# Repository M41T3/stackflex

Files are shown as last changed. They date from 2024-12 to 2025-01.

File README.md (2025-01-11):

# What is StackFlex?

**StackFlex** is a microcontroller system built around the Espressif ESP32-S3 Mini module. The heart of the system is the **Core PCB**, which houses the microprocessor and supports power delivery via USB or a LiPo battery. Additional functionalities can be seamlessly integrated through modular **Feature PCBs**, which are designed to stack on top of the Core PCB.

The StackFlex system is highly extensible and flexible, all within a compact 40 mm x 40 mm form factor. Leveraging the advanced capabilities of the ESP32-S3 — such as Bluetooth LE, WiFi, and more — the innovative stacking mechanism, and templates for custom Feature PCBs, the system offers virtually unlimited use cases, constrained only by your imagination.

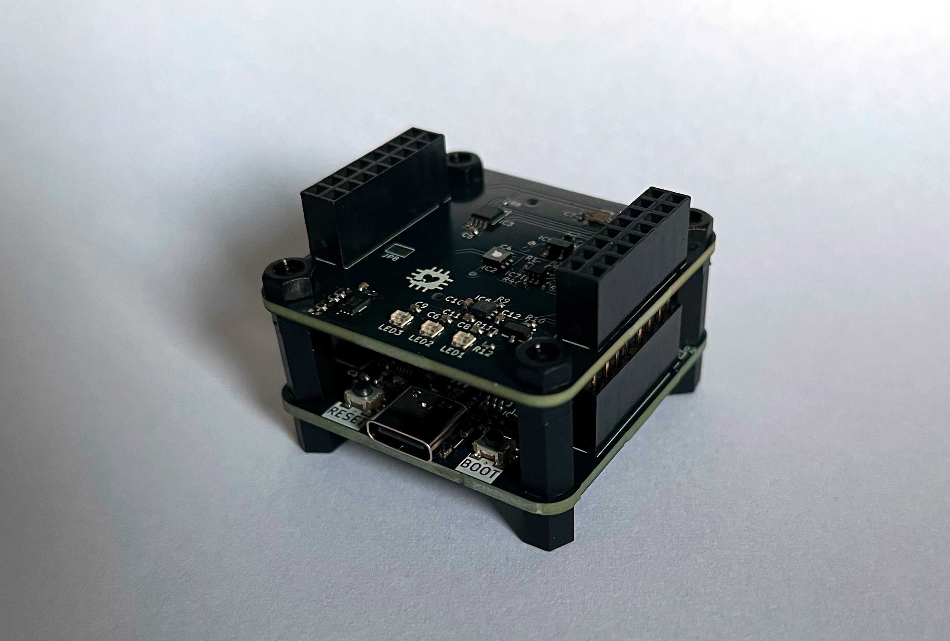
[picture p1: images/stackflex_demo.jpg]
System Image


# Contents

- KiCad Projects
- PDF Schematics
- JLCPCB Production Files (Gerber, BOM, CPL)
- StackFlex Arduino Library *[tbd]* 

# Core PCB Highlights

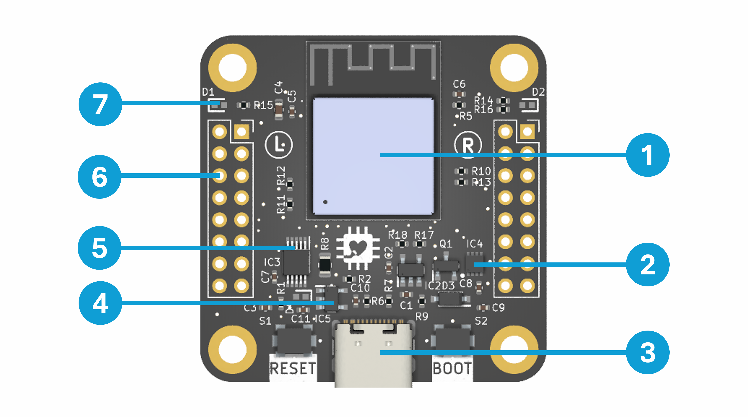
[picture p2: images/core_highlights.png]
Core Front


1. **ESP32-S3 Mini 1 Module:** Powerful and energy-efficient microcontroller featuring dual-core processing, integrated WiFi and Bluetooth LE connectivity, AI acceleration, and extensive peripheral support.

2. **3.7 V LiPo:** Power StackFlex using a LiPo battery with state-of-charge (SOC) monitoring.

3. **USB C Connector:** State of the art connector to programm and power the microcontroller and its peripherals.

4. **LiPo Charging:** LiPo charges via USB if it is connected.

5. **Power Monitoring:** Monitor the power consumption and current of stacked Feature PCBs.

6. **GPIO:** Rotationally symmetrical GPIOs for enhanced flexibility.

7. **LEDs:** Two status LEDs (red, green)

=> Detailed documentation [here](/pcb/stackflex_core/).

# Feature PCBs

Feature PCBs enhance the fucntionality of the StackFlex system. Here is a list of already developed Feature PCBs:

- [Air Quality Feature PCB](/pcb/stackflex_feature_air_qual/)
    - Gas Sensor (TVOC, eCO2)
    - Temperature
    - Ambient Light Sensor
    - WS2812B Status LEDs
- more to come..

# Feature PCB Template

Develop and build your own Feature PCB with the provided KiCad Template Project.

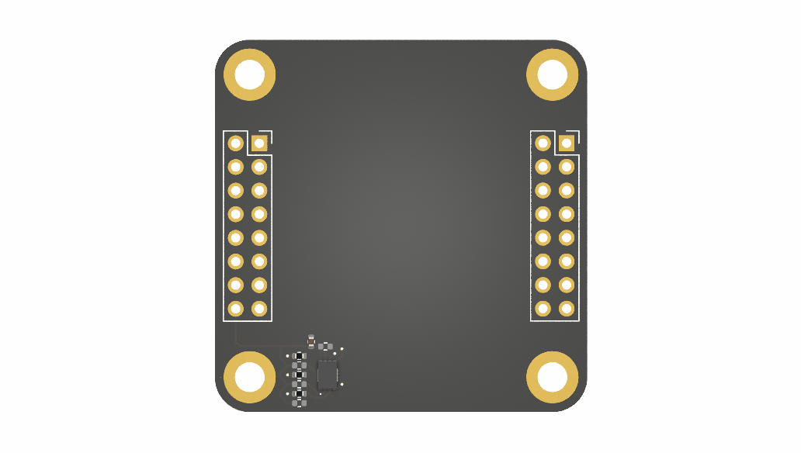
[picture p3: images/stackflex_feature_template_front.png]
Feature PCB Template


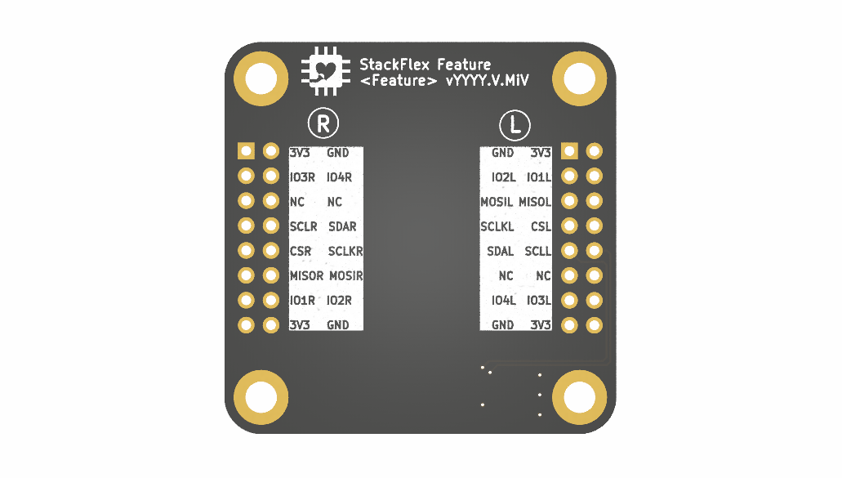
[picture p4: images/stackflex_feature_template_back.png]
Feature PCB Template


=> Detailed documentation [here](/pcb/stackflex_feature_template/).

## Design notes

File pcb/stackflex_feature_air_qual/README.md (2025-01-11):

# StackFlex Air Quality Feature PCB

**Sensors**:

- [LM75 Temperature Sensor](https://www.analog.com/media/en/technical-documentation/data-sheets/lm75.pdf)
- [OPT3001 Ambient Light Sensor (ALS)](https://www.ti.com/lit/ds/symlink/opt3001.pdf?ts=1736604398451)
- [SGP30 Indoor Air Quality Sensor](https://sensirion.com/media/documents/984E0DD5/61644B8B/Sensirion_Gas_Sensors_Datasheet_SGP30.pdf)

See schematic for further information.

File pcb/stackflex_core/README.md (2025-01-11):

# StackFlex Core

**Pinout:** 

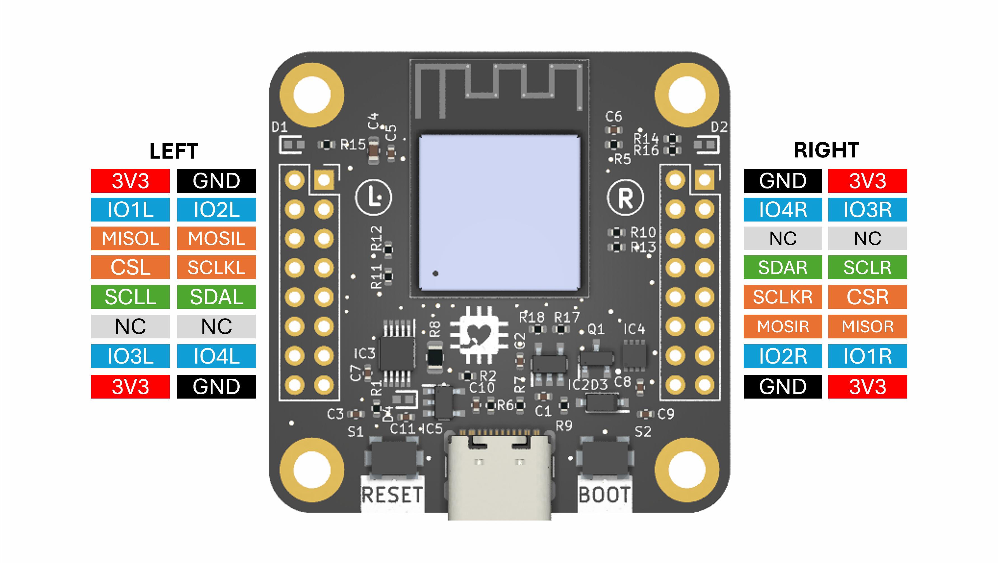
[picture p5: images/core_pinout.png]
Core Front


**Backside:**

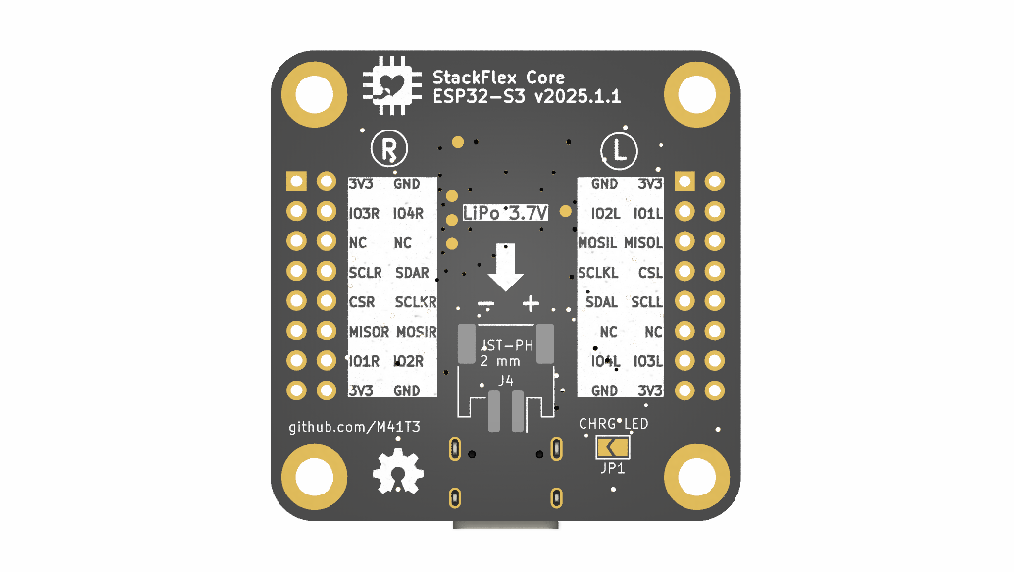
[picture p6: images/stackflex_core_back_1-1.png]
Core Back


- JST-PH 2mm Connector Footprint for LiPo (check polarity)

**ICs:**
- [ESP32-S3 Mini](https://www.espressif.com/sites/default/files/documentation/esp32-s3-mini-1_mini-1u_datasheet_en.pdf)
- [INA226 Current Sensor](https://www.ti.com/lit/ds/symlink/ina226.pdf)
- [TP4054 Battery Charger](https://www.laskakit.cz/user/related_files/tp4054.pdf)
- [MAX17048 Battery Fuel Gauge](https://www.analog.com/media/en/technical-documentation/data-sheets/MAX17048-MAX17049.pdf)

See schematic for further information.

**Assembly:**

- Pinheader 2x8 2.54 mm
- M3 Spacer

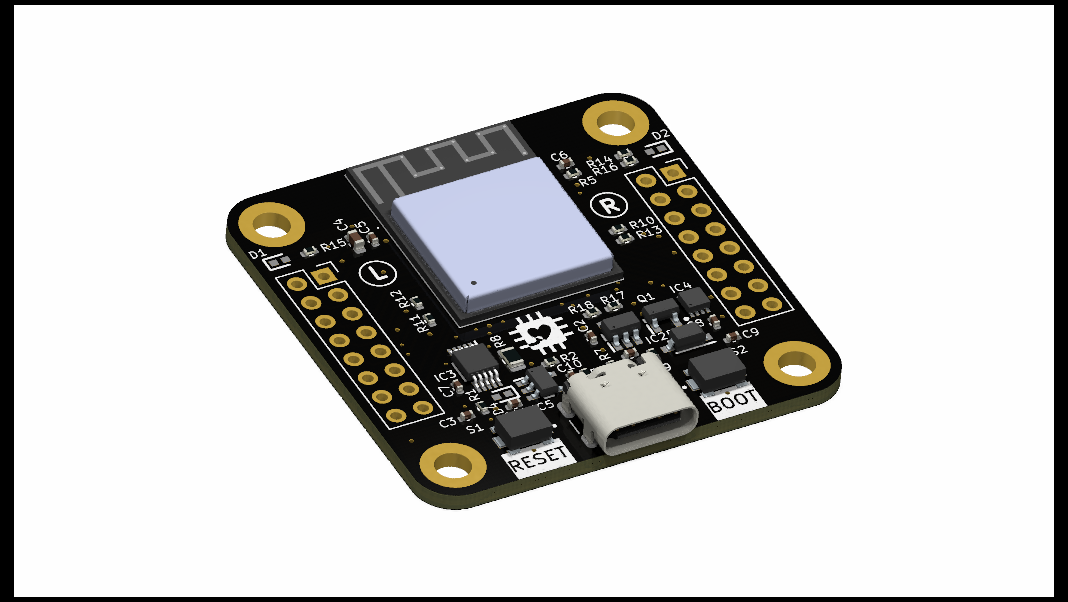
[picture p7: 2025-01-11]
images/stackflex_core_side_1-1.png

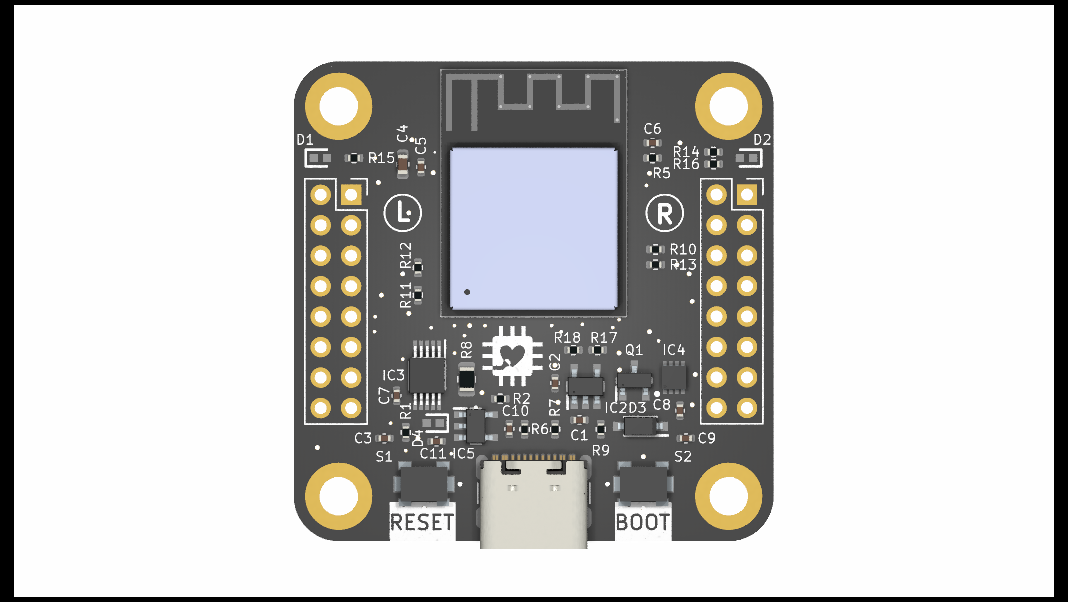
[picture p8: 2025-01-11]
images/stackflex_core_front_1-1.png

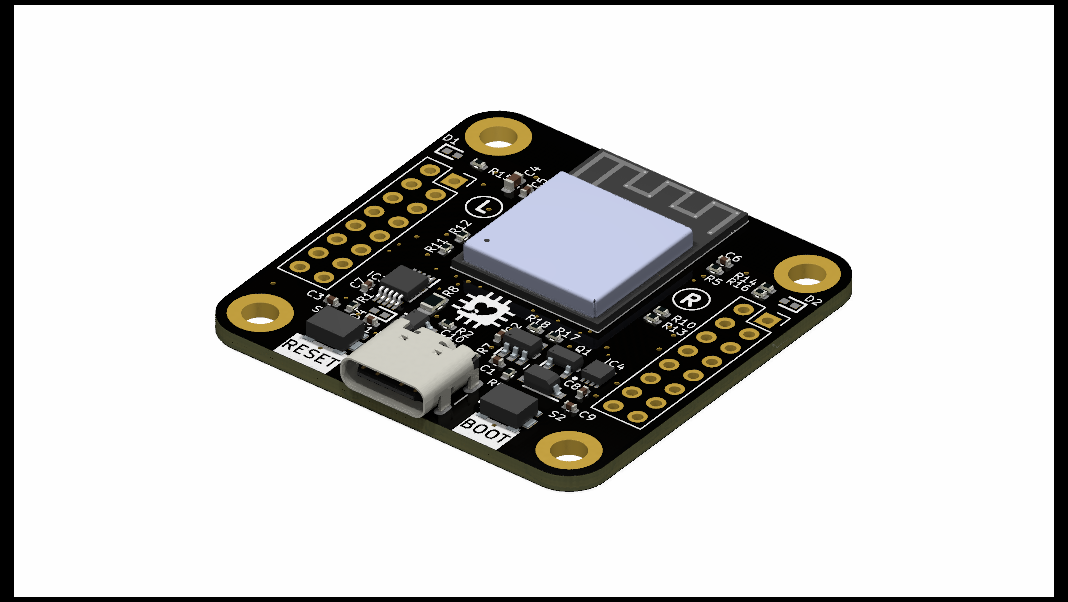
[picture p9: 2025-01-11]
images/stackflex_core_side2_1-1.png

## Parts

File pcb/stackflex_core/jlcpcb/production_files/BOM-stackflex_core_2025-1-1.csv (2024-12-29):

Comment | Designator | Footprint | LCSC | Quantity
1k | R1 | R_0402_1005Metric | C11702 | 1
0.1uF | C3,C5,C6,C7,C8,C9 | C_0402_1005Metric | C1525 | 6
10uF | C1,C11 | C_0402_1005Metric | C15525 | 2
USB_C_Receptacle_USB2.0_16P | J1 | USB_C_Receptacle_GCT_USB4105-xx-A_16P_TopMnt_Horizontal | C165948 | 1
PTS820J25MSMTRLFS | S1,S2 | PTS820J25MSMTRLFS | C221900 | 2
33 mOhm 1% 250mW | R8 | R_0805_2012Metric | C247604 | 1
330 | R14,R16 | R_0402_1005Metric | C25104 | 2
33 | R15 | R_0402_1005Metric | C25105 | 1
100k | R9 | R_0402_1005Metric | C25741 | 1
10k | R5 | R_0402_1005Metric | C25744 | 1
4.7k | R10,R11,R12,R13,R17,R18 | R_0402_1005Metric | C25900 | 6
5.1k 1% | R6,R7 | R_0402_1005Metric | C25905 | 2
MAX17048G+T10 | IC4 | SON50P200X200X80-9N-D | C2682616 | 1
ESP32-S3-MINI-1-N8 | IC1 | ESP32S3MINI1N8 | C2913206 | 1
2k | R2 | R_0402_1005Metric | C4109 | 1
DMP2045U-7 | Q1 | SOT96P240X115-3N | C459541 | 1
INA226AIDGSR | IC3 | SOP50P490X110-10N | C49851 | 1
AP2112K-3.3TRG1 | IC2 | SOT95P285X140-5N | C51118 | 1
1uF | C10,C2 | C_0402_1005Metric | C52923 | 2
22uF | C4 | C_0603_1608Metric | C59461 | 1
TP4054 | IC5 | SOT95P280X100-5N | C668215 | 1
green | D1,D4 | LEDC1005X55N | C71911 | 2
red | D2 | LEDC1005X55N | C74338 | 1
1N5819HW-7-F | D3 | SOD3716X145N | C82544 | 1

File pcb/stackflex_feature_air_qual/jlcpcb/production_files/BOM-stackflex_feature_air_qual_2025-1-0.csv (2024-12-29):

Comment | Designator | Footprint | LCSC | Quantity
BSS138BK | Q3 | TL431CDBZR215 | C112239 | 1
2.2uF | C11,C12 | C_0402_1005Metric | C12530 | 2
0.1uF | C1,C5,C6,C7,C8,C9 | C_0402_1005Metric | C1525 | 6
SolderJumper_2_Open | JP2,JP5,JP7 | R_0402_1005Metric | C17168 | 3
TPS60150DRVR | IC6 | SON65P200X200X80-7N | C182429 | 1
BSS138PS | IC7 | SOT65P210X110-6N | C193381 | 1
4.7uF | C10 | C_0402_1005Metric | C23733 | 1
470 | R12 | R_0402_1005Metric | C25117 | 1
10k | R1,R10,R11,R2,R3,R4,R7,R8,R9 | R_0402_1005Metric | C25744 | 9
LM75BDP,118 | IC3 | SOP65P490X110-8N | C33099 | 1
XL-0807RGBC-WS2812B | LED1,LED2,LED3 | XL0807RGBCWS2812B | C3646929 | 3
M24C02-RMC6TG | IC1 | M24C16RMC6TG | C495258 | 1
SGP30-2.5k | IC2 | SON80P245X245X90-7N | C514454 | 1
1uF | C2,C3,C4 | C_0402_1005Metric | C52923 | 3
TLV70018DDCR | IC5 | SOT95P280X110-5N | C79924 | 1
OPT3001DNPR | IC4 | SON65P200X200X65-7N-D | C90462 | 1

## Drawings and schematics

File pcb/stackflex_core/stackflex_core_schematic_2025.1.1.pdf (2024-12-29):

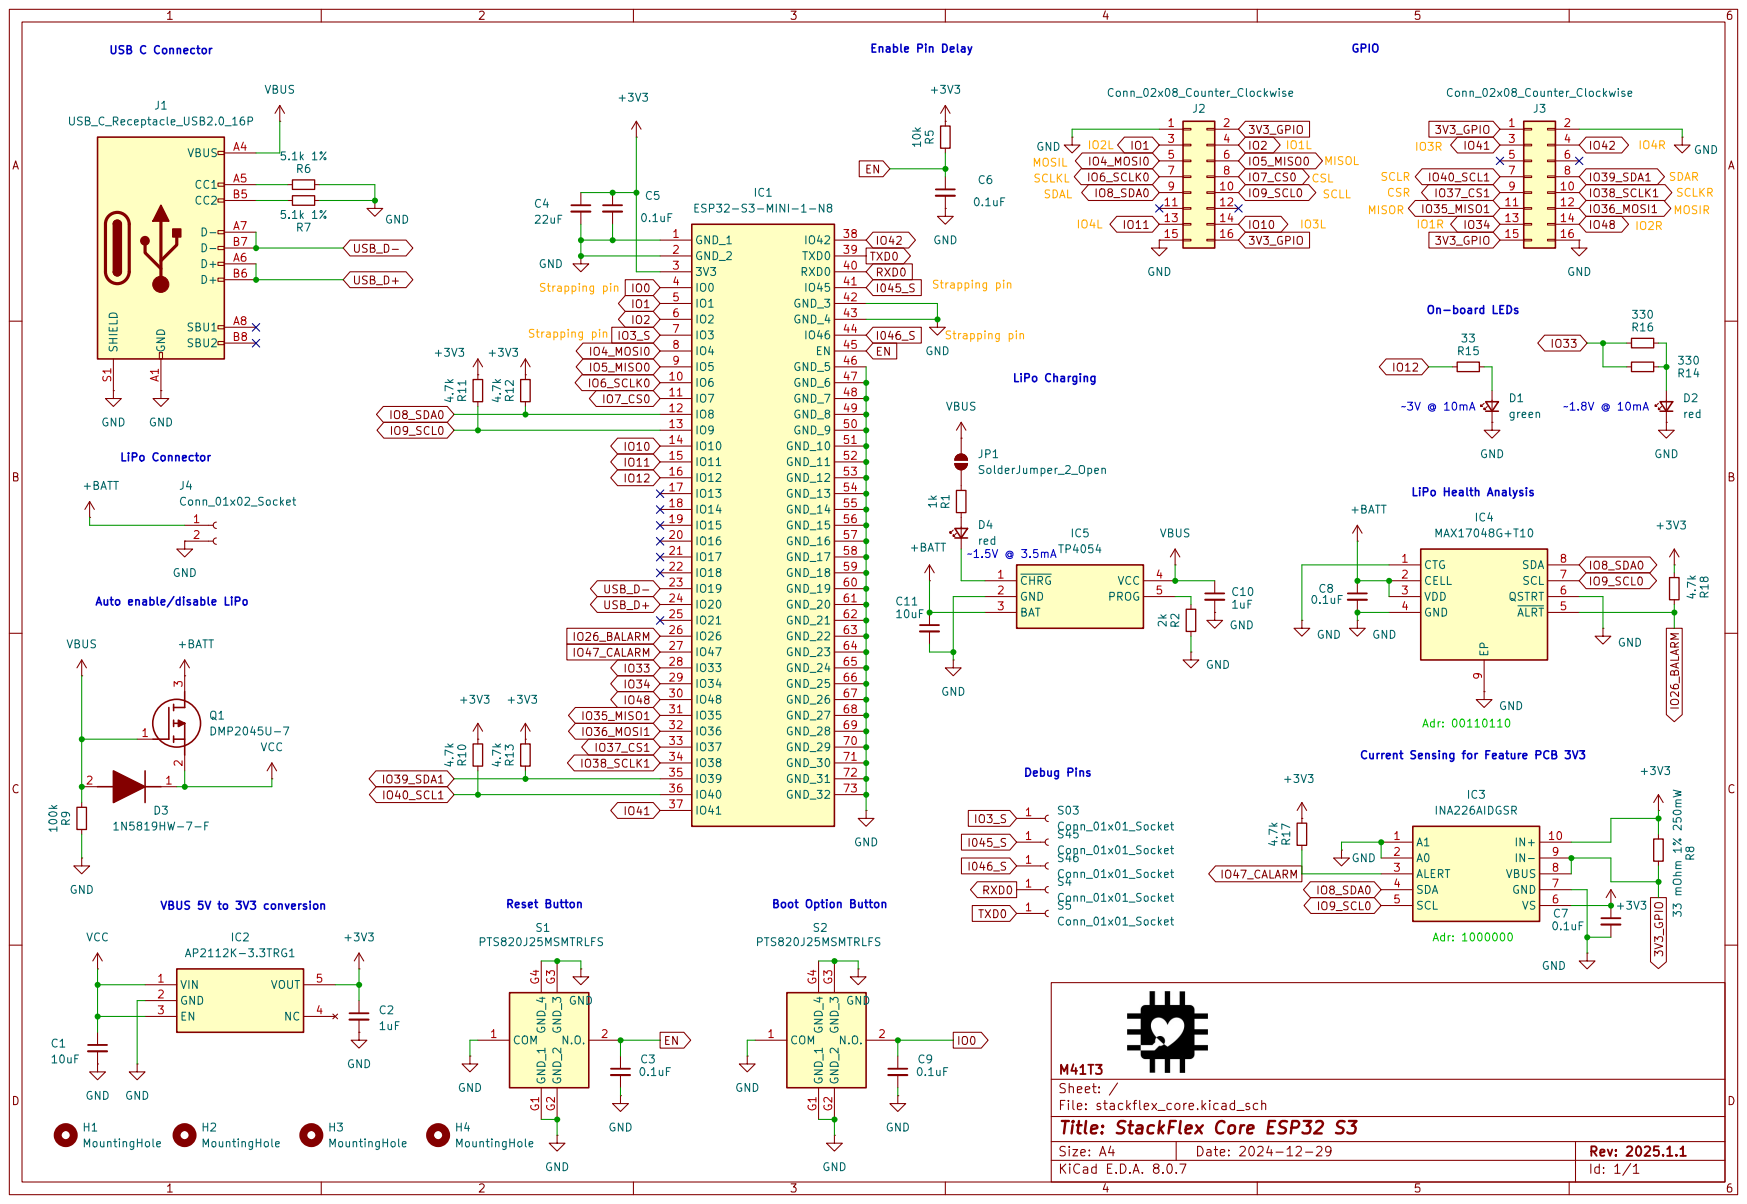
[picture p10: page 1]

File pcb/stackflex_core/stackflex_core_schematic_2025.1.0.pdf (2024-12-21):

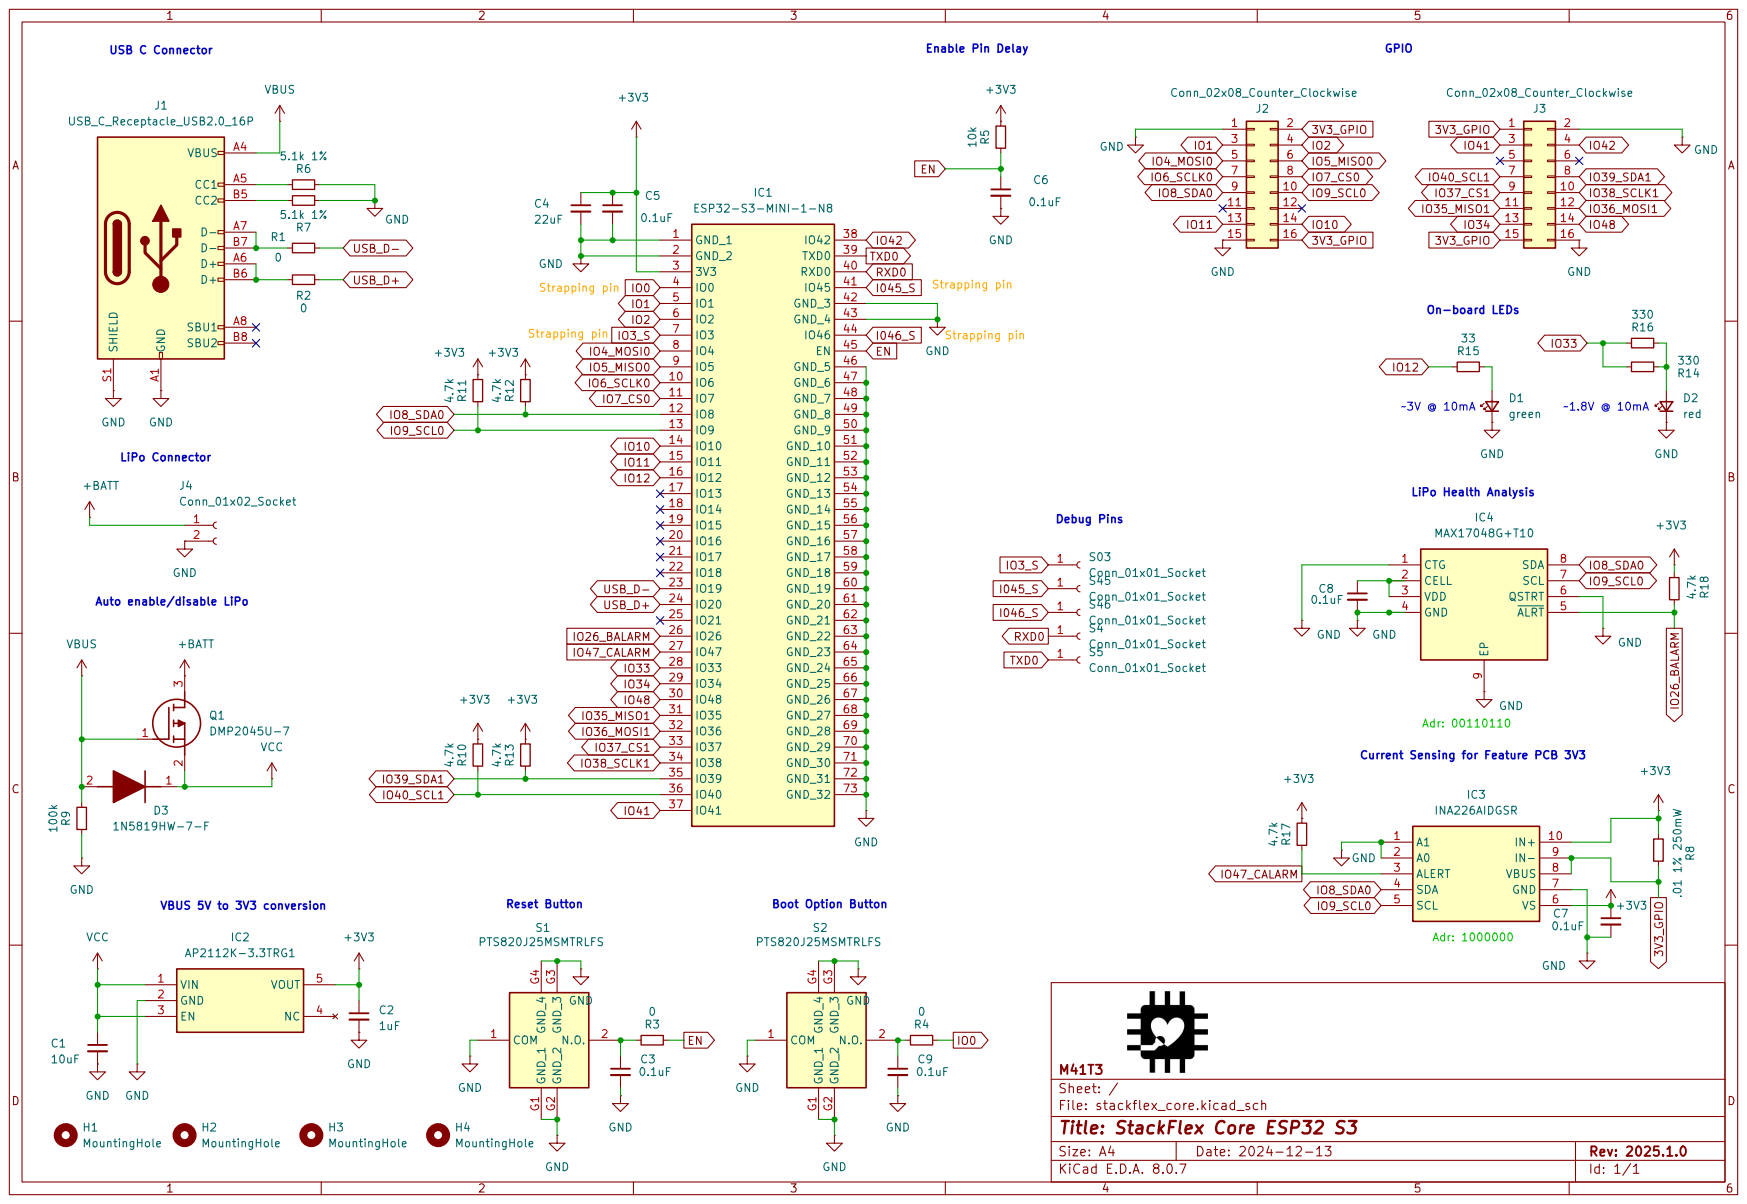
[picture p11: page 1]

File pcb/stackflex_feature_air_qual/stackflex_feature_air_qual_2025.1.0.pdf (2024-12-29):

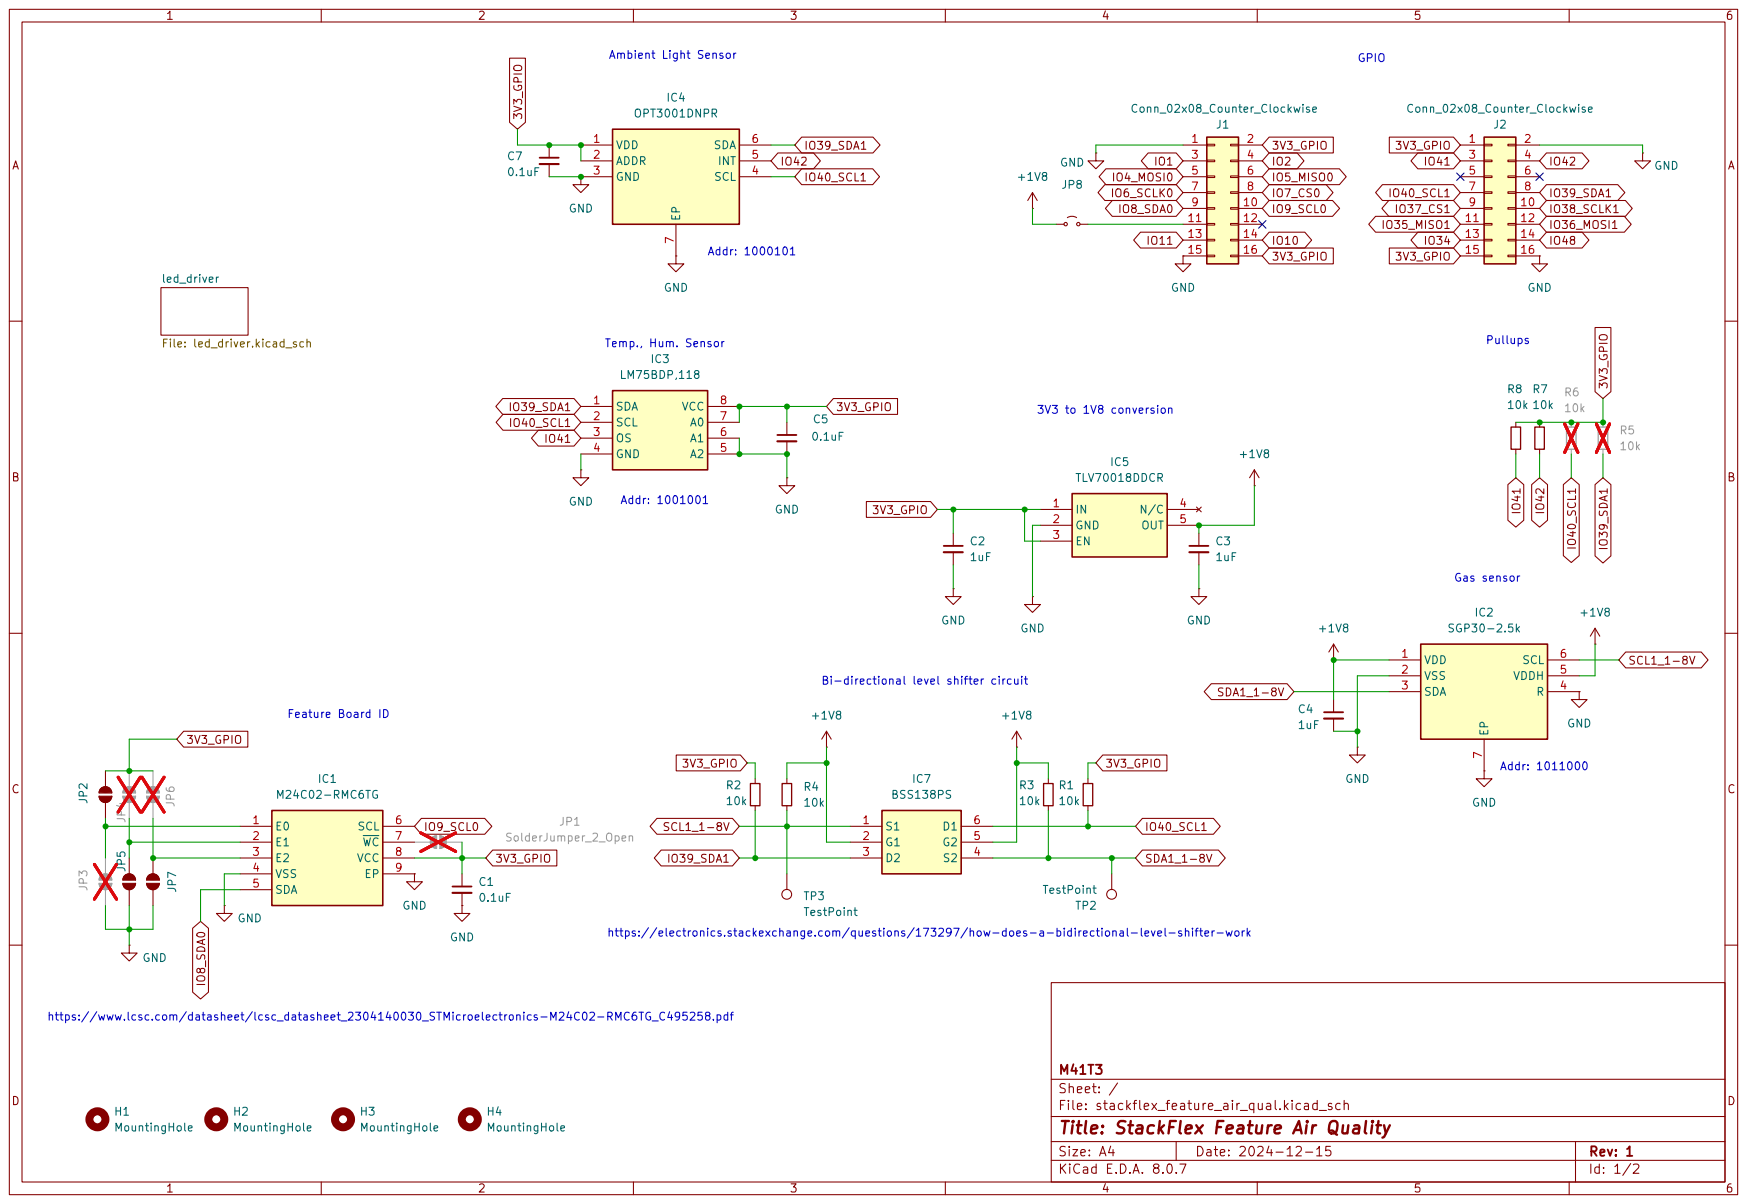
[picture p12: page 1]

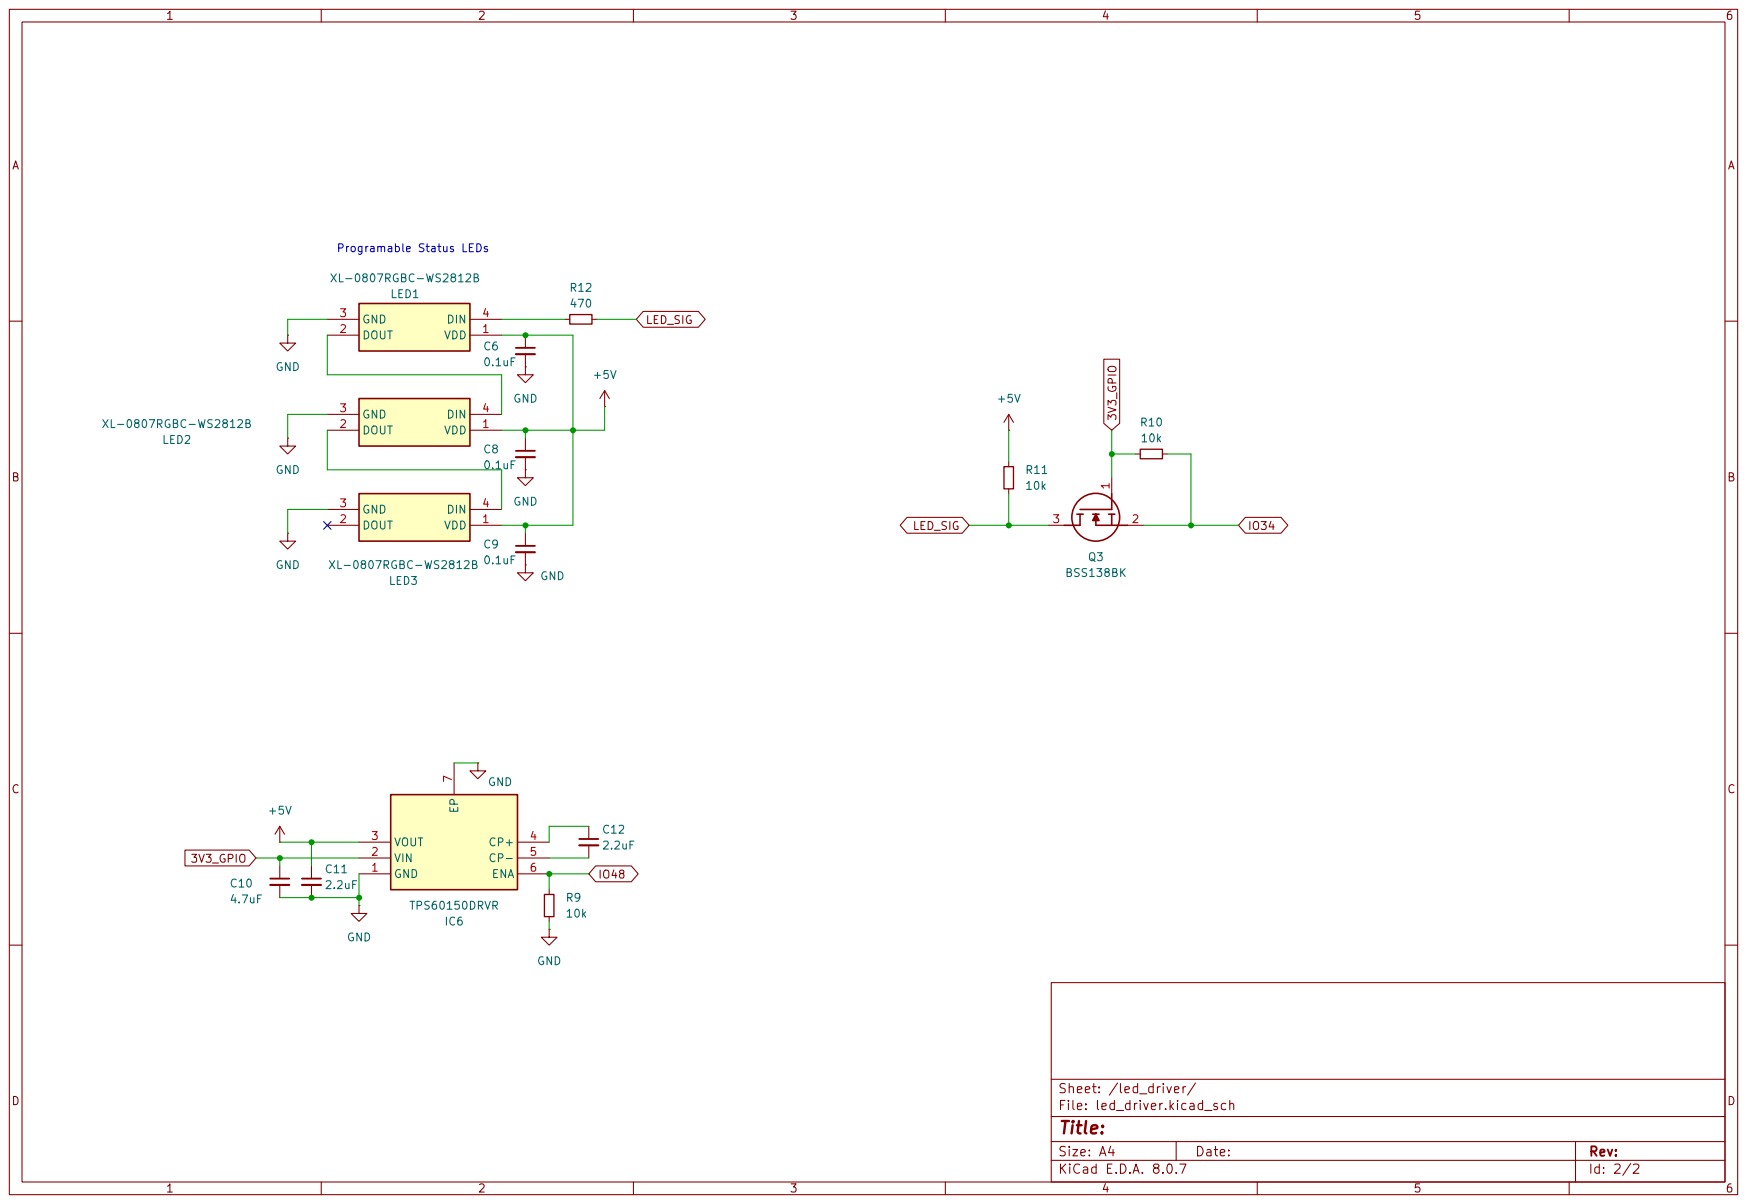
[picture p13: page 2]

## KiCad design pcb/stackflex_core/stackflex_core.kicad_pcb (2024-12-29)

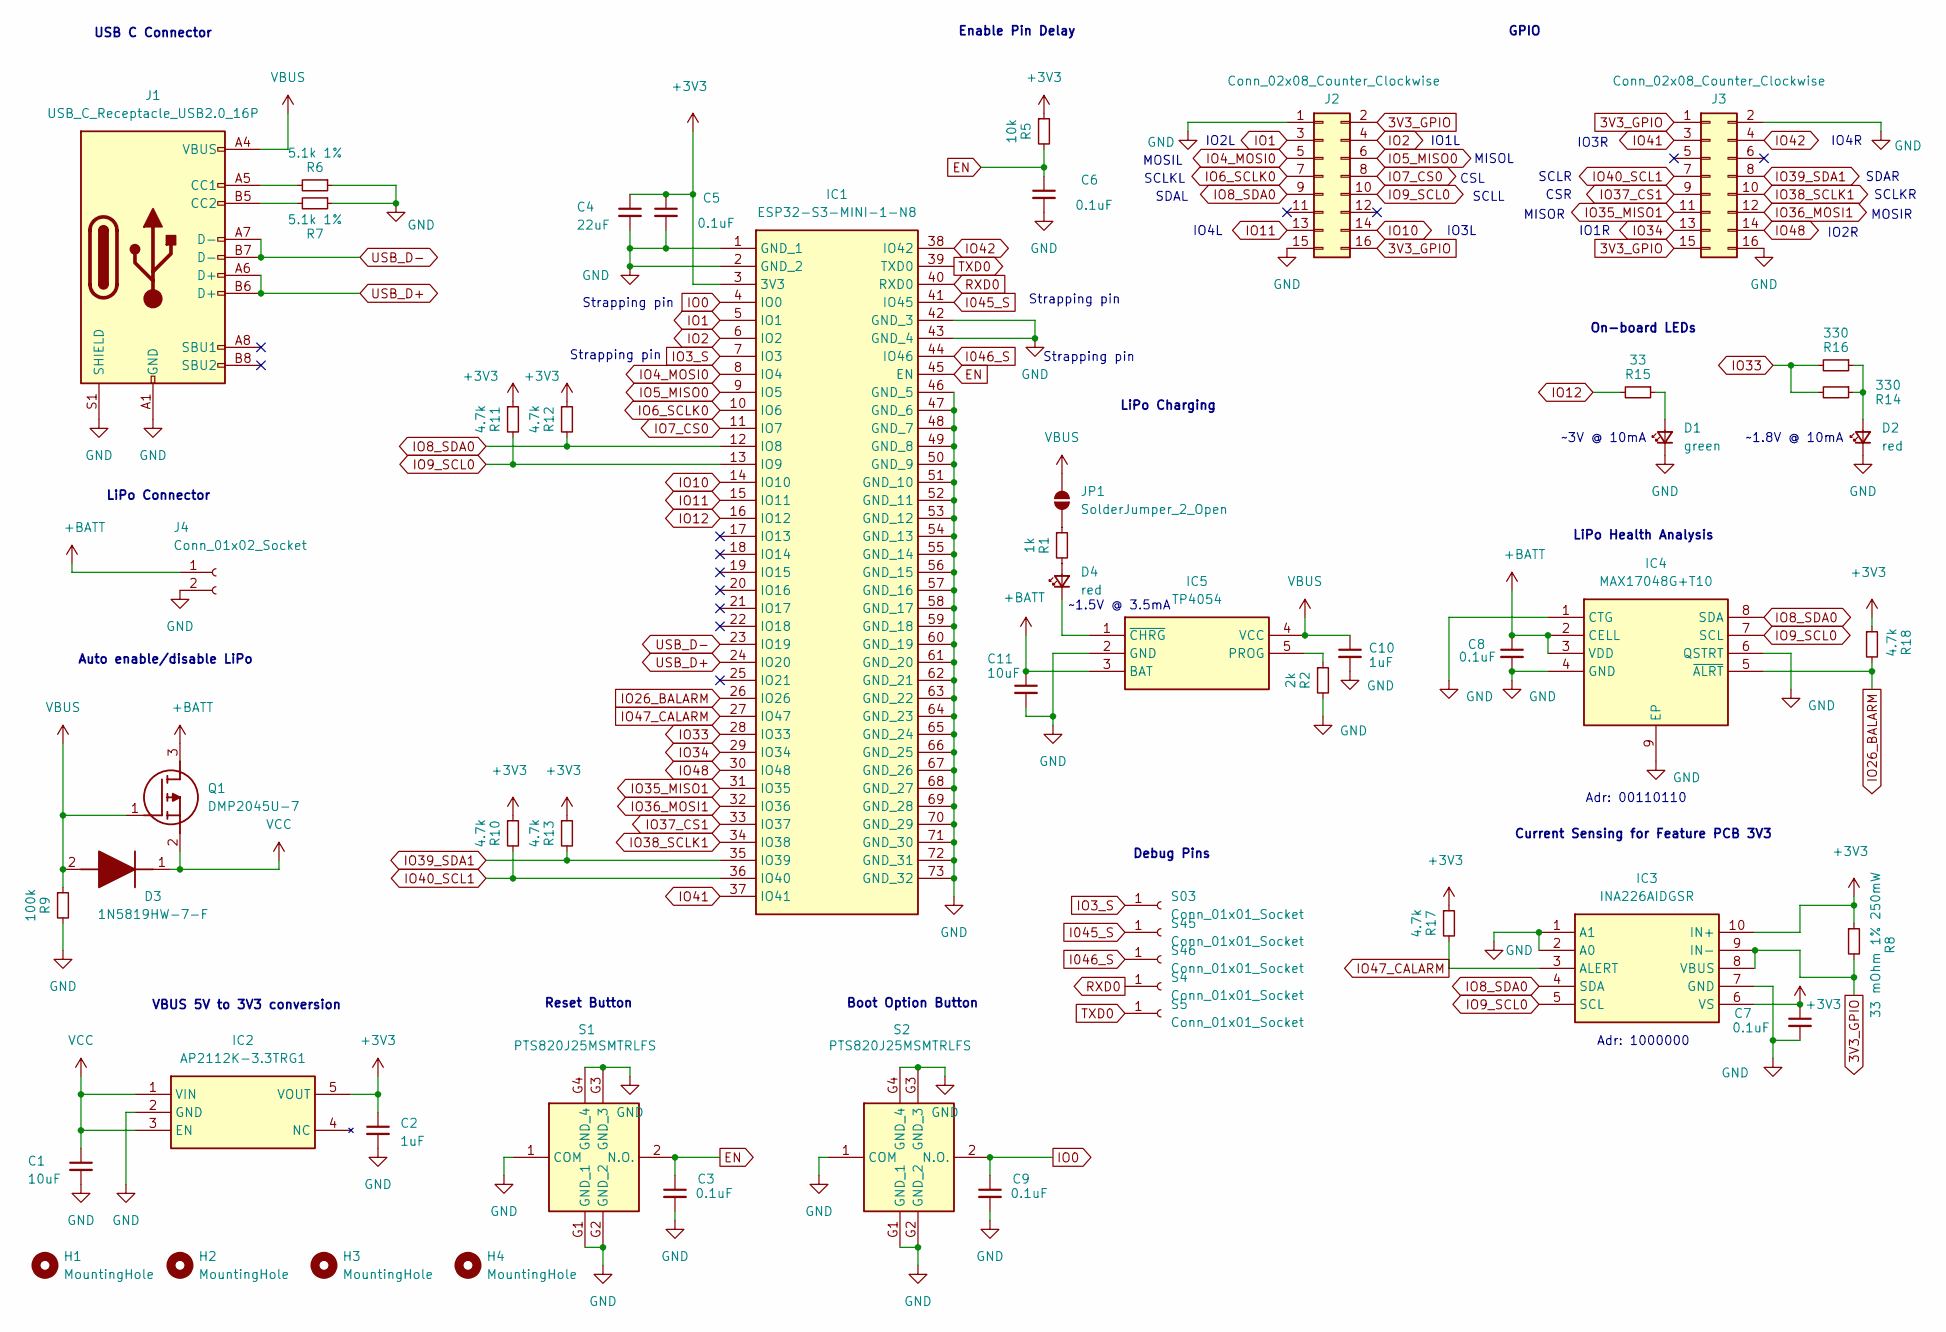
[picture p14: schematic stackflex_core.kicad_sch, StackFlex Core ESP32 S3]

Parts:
C1, C11: 10uF; C_0402_1005Metric
C2, C10: 1uF; C_0402_1005Metric
C3, C5, C6, C7, C8, C9: 0.1uF; C_0402_1005Metric
C4: 22uF; C_0603_1608Metric
D1: green; LEDC1005X55N
D2, D4: red; LEDC1005X55N
D3: 1N5819HW-7-F; SOD3716X145N; Mouser Part Number 621-1N5819HW-F
H1, H2, H3, H4: MountingHole; MountingHole_3.2mm_M3_DIN965_Pad
IC1: ESP32-S3-MINI-1-N8; ESP32S3MINI1N8; Mouser Part Number 356-ESP32-S3-MINI1N8
IC2: AP2112K-3.3TRG1; SOT95P285X140-5N; Mouser Part Number 621-AP2112K-3.3TRG1
IC3: INA226AIDGSR; SOP50P490X110-10N; Mouser Part Number 595-INA226AIDGSR
IC4: MAX17048G+T10; SON50P200X200X80-9N-D; Mouser Part Number 700-MAX17048G+T10
IC5: TP4054; SOT95P280X100-5N; Manufacturer_Part_Number TP4054
J1: USB_C_Receptacle_USB2.0_16P; USB_C_Receptacle_GCT_USB4105-xx-A_16P_TopMnt_Horizontal
J2, J3: Conn_02x08_Counter_Clockwise; PinSocket_2x08_P2.54mm_Vertical
J4: Conn_01x02_Socket; JST_PH_S2B-PH-SM4-TB_1x02-1MP_P2.00mm_Horizontal
JP1: SolderJumper_2_Open; SolderJumper-2_P1.3mm_Open_TrianglePad1.0x1.5mm
Q1: DMP2045U-7; SOT96P240X115-3N; Mouser Part Number 621-DMP2045U-7
R1: 1k; R_0402_1005Metric
R2: 2k; R_0402_1005Metric
R5: 10k; R_0402_1005Metric
R6, R7: 5.1k 1%; R_0402_1005Metric
R8: 33 mOhm 1% 250mW; R_0805_2012Metric
R9: 100k; R_0402_1005Metric
R10, R11, R12, R13, R17, R18: 4.7k; R_0402_1005Metric
R14, R16: 330; R_0402_1005Metric
R15: 33; R_0402_1005Metric
S1, S2: PTS820J25MSMTRLFS; Mouser Part Number 611-PTS820J25MSMTR
S03, S4, S5, S45, S46: Conn_01x01_Socket; TestPoint_Pad_D1.0mm

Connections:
3V3_GPIO: IC3.8 (VBUS), IC3.9 (IN-), J2.2, J2.16, J3.1, J3.15, R8.2
+3V3: C2.1, C4.1, C5.1, C7.1, IC1.3 (3V3), IC2.5 (VOUT), IC3.6 (VS), IC3.10 (IN+), R5.1, R8.1, R10.1, R11.1, R12.1, R13.1, R17.1, R18.1
+BATT: C8.1, C11.1, IC4.2 (CELL), IC4.3 (VDD), IC5.3 (BAT), J4.1, Q1.3 (D)
EN: C3.1, C6.1, IC1.45 (EN), R5.2, S1.2 (N.O.)
GND: C1.2, C2.2, C3.2, C4.2, C5.2, C6.2, C7.2, C8.2, C9.2, C10.2, C11.2, D1.1 (K), D2.1 (K), IC1.1 (GND_1), IC1.2 (GND_2), IC1.42 (GND_3), IC1.43 (GND_4), IC1.46 (GND_5), IC1.47 (GND_6), IC1.48 (GND_7), IC1.49 (GND_8), IC1.50 (GND_9), IC1.51 (GND_10), IC1.52 (GND_11), IC1.53 (GND_12), IC1.54 (GND_13), IC1.55 (GND_14), IC1.56 (GND_15), IC1.57 (GND_16), IC1.58 (GND_17), IC1.59 (GND_18), IC1.60 (GND_19), IC1.61 (GND_20), IC1.62 (GND_21), IC1.63 (GND_22), IC1.64 (GND_23), IC1.65 (GND_24), IC1.66 (GND_25), IC1.67 (GND_26), IC1.68 (GND_27), IC1.69 (GND_28), IC1.70 (GND_29), IC1.71 (GND_30), IC1.72 (GND_31), IC1.73 (GND_32), IC2.2 (GND), IC3.1 (A1), IC3.2 (A0), IC3.7 (GND), IC4.1 (CTG), IC4.4 (GND), IC4.6 (QSTRT), IC4.9 (EP), IC5.2 (GND), J1.A1 (GND), J1.A12 (GND), J1.B1 (GND), J1.B12 (GND), J1.S1 (SHIELD), J2.1, J2.15, J3.2, J3.16, J4.2, R2.2, R6.1, R7.1, R9.2, S1.1 (COM), S1.G1 (GND_1), S1.G2 (GND_2), S1.G3 (GND_3), S1.G4 (GND_4), S2.1 (COM), S2.G1 (GND_1), S2.G2 (GND_2), S2.G3 (GND_3), S2.G4 (GND_4)
I045_S: IC1.41 (IO45), S45.1
I046_S: IC1.44 (IO46), S46.1
IO0: C9.1, IC1.4 (IO0), S2.2 (N.O.)
IO1: IC1.5 (IO1), J2.3
IO2: IC1.6 (IO2), J2.4
IO3_S: IC1.7 (IO3), S03.1
IO4_MOSI0: IC1.8 (IO4), J2.5
IO5_MISO0: IC1.9 (IO5), J2.6
IO6_SCLK0: IC1.10 (IO6), J2.7
IO7_CS0: IC1.11 (IO7), J2.8
IO8_SDA0: IC1.12 (IO8), IC3.4 (SDA), IC4.8 (SDA), J2.9, R12.2
IO9_SCL0: IC1.13 (IO9), IC3.5 (SCL), IC4.7 (SCL), J2.10, R11.2
IO10: IC1.14 (IO10), J2.14
IO11: IC1.15 (IO11), J2.13
IO12: IC1.16 (IO12), R15.2
IO26_BALARM: IC1.26 (IO26), IC4.5 (~ALRT), R18.2
IO33: IC1.28 (IO33), R14.2, R16.2
IO34: IC1.29 (IO34), J3.13
IO35_MISO1: IC1.31 (IO35), J3.11
IO36_MOSI1: IC1.32 (IO36), J3.12
IO37_CS1: IC1.33 (IO37), J3.9
IO38_SCLK1: IC1.34 (IO38), J3.10
IO39_SDA1: IC1.35 (IO39), J3.8, R13.2
IO40_SCL1: IC1.36 (IO40), J3.7, R10.2
IO41: IC1.37 (IO41), J3.3
IO42: IC1.38 (IO42), J3.4
IO47_CALARM: IC1.27 (IO47), IC3.3 (ALERT), R17.2
IO48: IC1.30 (IO48), J3.14
unnamed: D1.2 (A), R15.1
unnamed: D2.2 (A), R14.1, R16.1
unnamed: D4.2 (A), R1.2
unnamed: D4.1 (K), IC5.1 (~CHRG)
unnamed: IC5.5 (PROG), R2.1
unnamed: J1.A5 (CC1), R6.2
unnamed: J1.B5 (CC2), R7.2
unnamed: JP1.1 (A), R1.1
RXD0: IC1.40 (RXD0), S4.1
TXD0: IC1.39 (TXD0), S5.1
USB_D+: IC1.24 (IO20), J1.A6 (D+), J1.B6 (D+)
USB_D-: IC1.23 (IO19), J1.A7 (D-), J1.B7 (D-)
VBUS: C10.1, D3.2 (A), IC5.4 (VCC), J1.A4 (VBUS), J1.A9 (VBUS), J1.B4 (VBUS), J1.B9 (VBUS), JP1.2 (B), Q1.1 (G), R9.1
VCC: C1.1, D3.1 (K), IC2.1 (VIN), IC2.3 (EN), Q1.2 (S)

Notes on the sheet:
IO2L
Enable Pin Delay
IO2R
IO1L
~3V @ 10mA
VBUS 5V to 3V3 conversion
IO1R
Strapping pin
Reset Button
USB C Connector
MOSIR
CSL
SCLL
SCLKL
MOSIL
Auto enable/disable LiPo
SCLKR
MISOL
IO3R
IO4L
Adr: 00110110
~1.5V @ 3.5mA
MISOR
Adr: 1000000
LiPo Charging
SDAR
Debug Pins
IO4R
~1.8V @ 10mA
LiPo Health Analysis
LiPo Connector
CSR
IO3L
Current Sensing for Feature PCB 3V3
GPIO
On-board LEDs
SCLR
SDAL
Boot Option Button

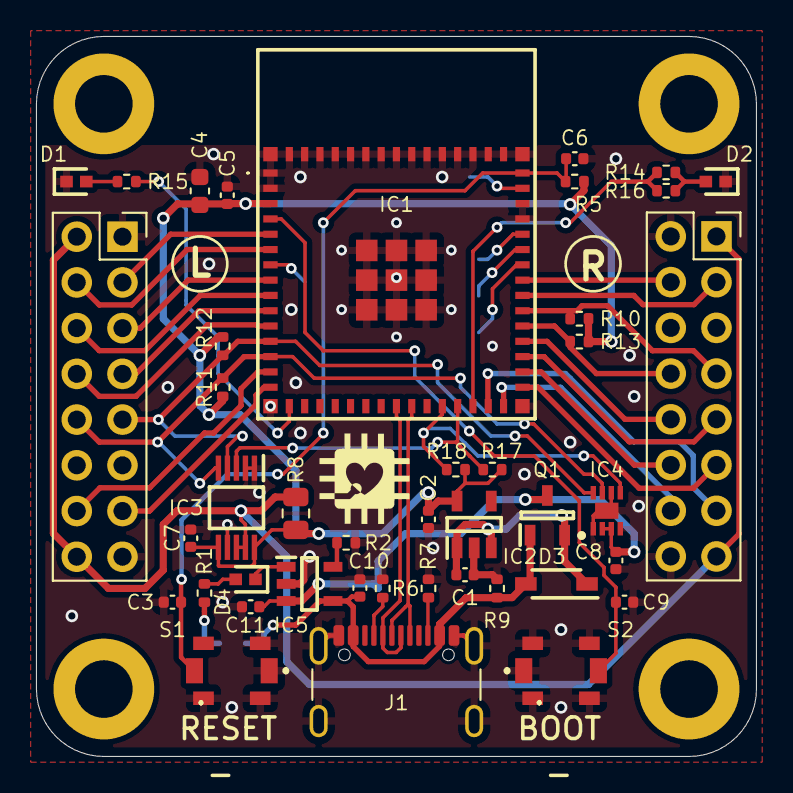
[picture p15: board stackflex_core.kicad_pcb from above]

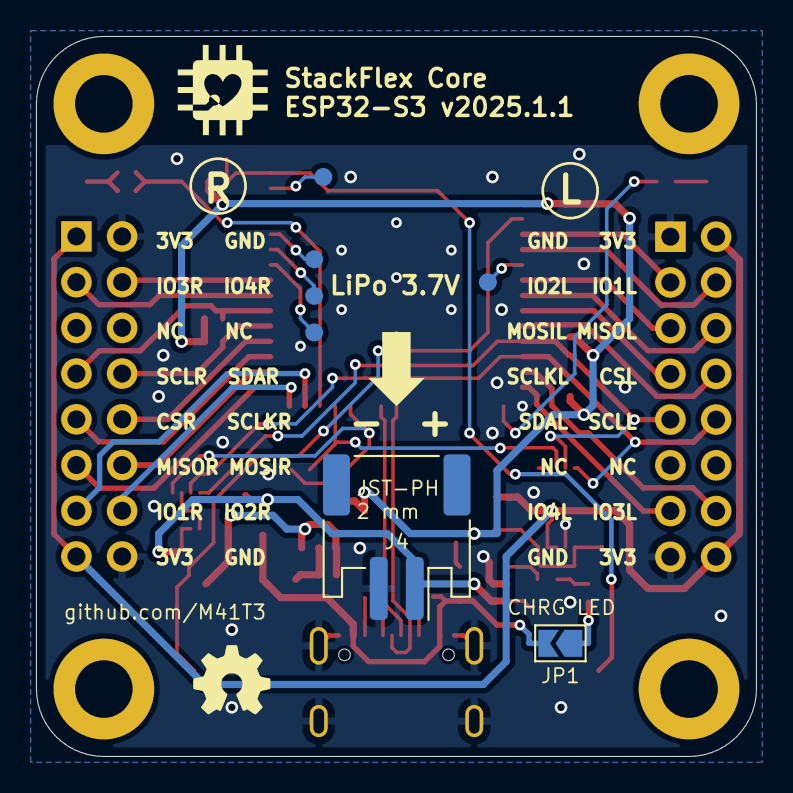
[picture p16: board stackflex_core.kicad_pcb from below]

Board: 2 copper layers, 40.0 x 40.0 mm, 53 parts (7 on the bottom side), 47 nets.

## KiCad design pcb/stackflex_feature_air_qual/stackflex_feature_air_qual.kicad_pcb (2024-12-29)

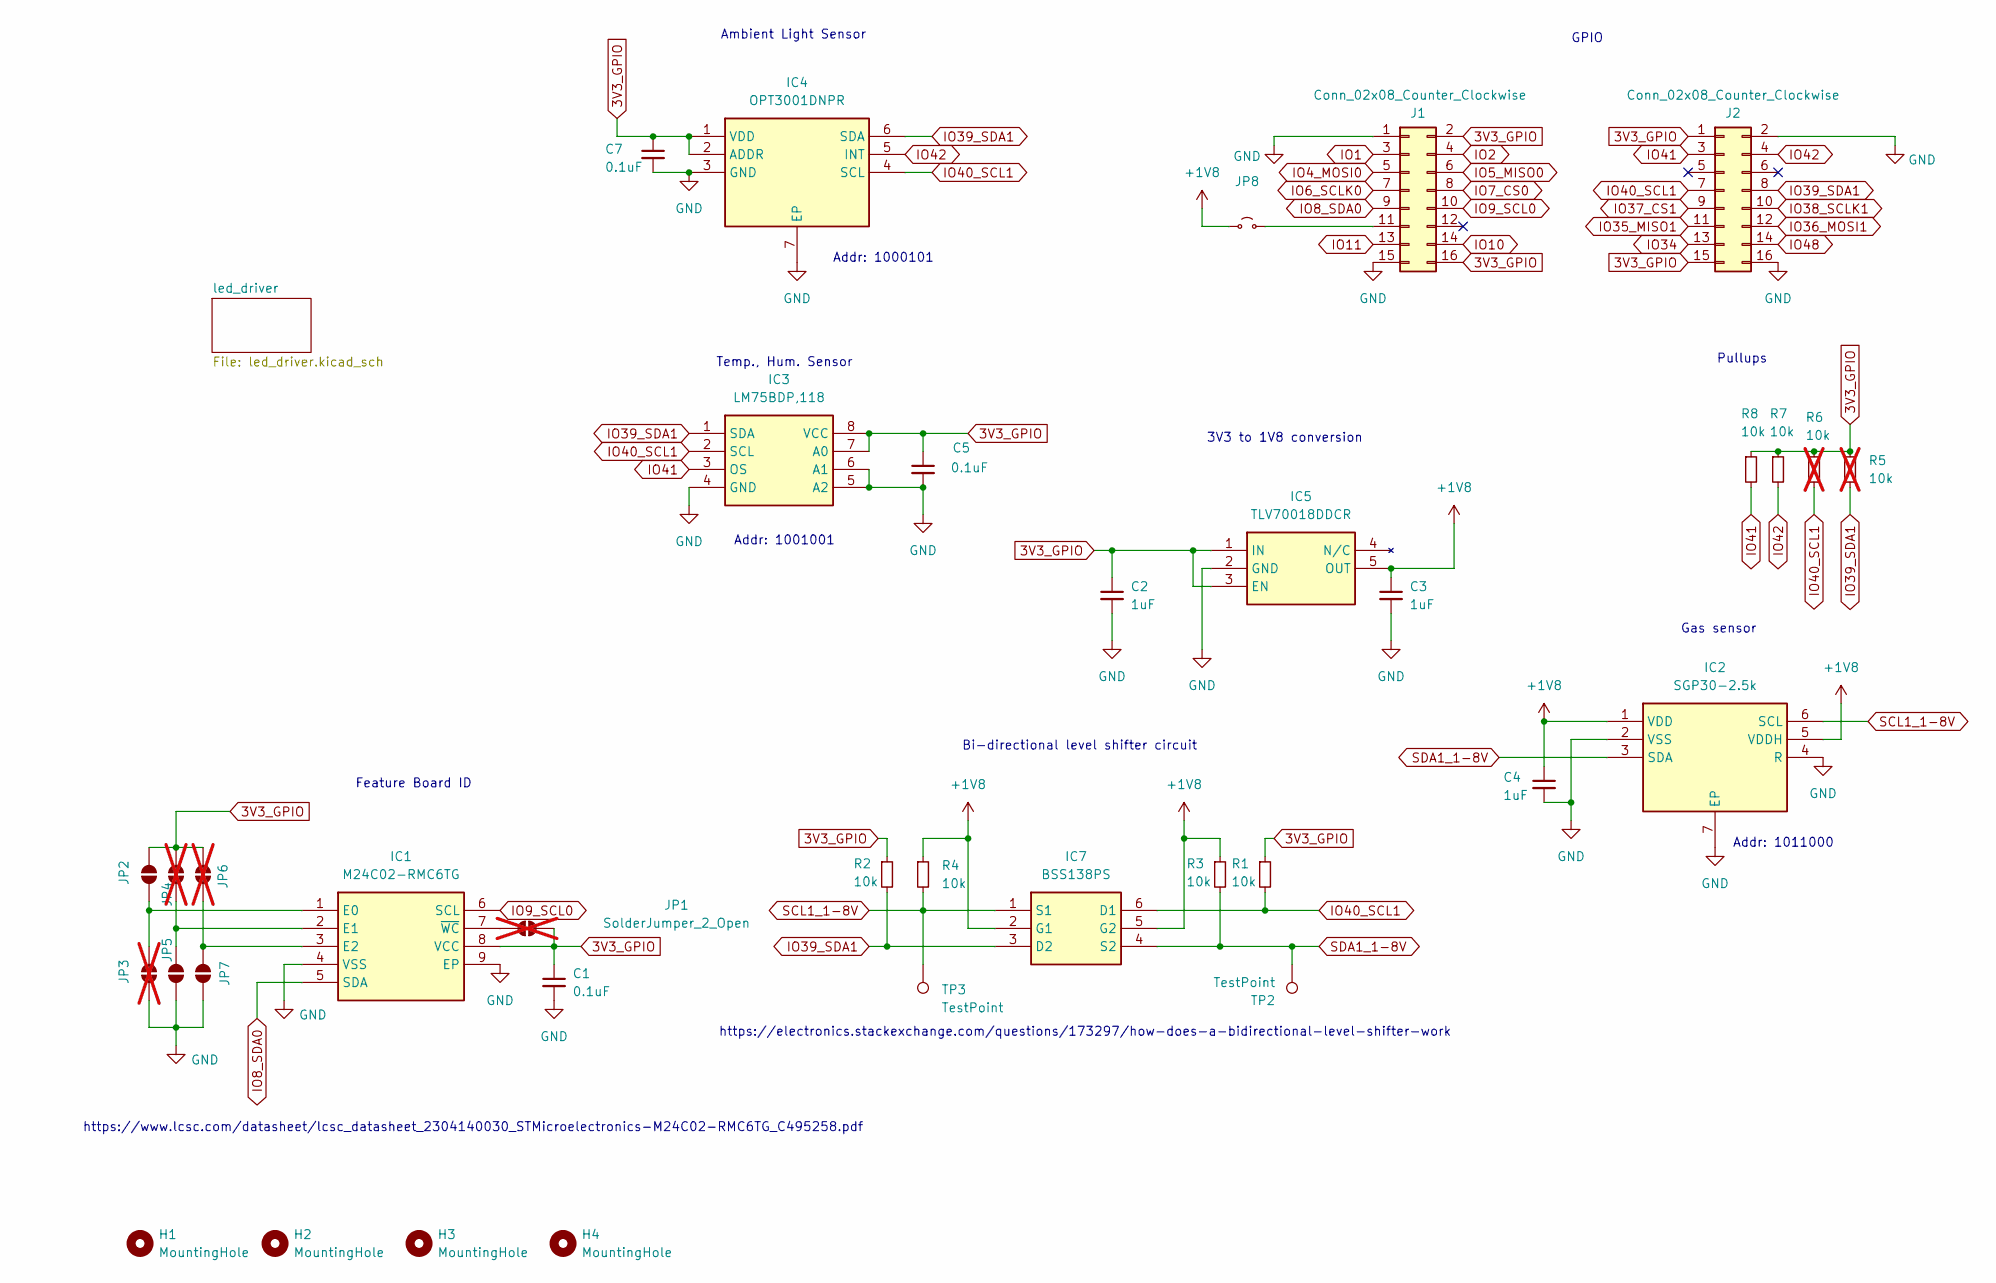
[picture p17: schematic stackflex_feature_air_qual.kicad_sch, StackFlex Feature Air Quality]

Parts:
C1, C5, C7: 0.1uF; C_0402_1005Metric
C2, C3, C4: 1uF; C_0402_1005Metric
H1, H2, H3, H4: MountingHole; MountingHole_3.2mm_M3_DIN965_Pad
IC1: M24C02-RMC6TG; M24C16RMC6TG; Mouser Part Number 511-M24C16-RMC6TG
IC2: SGP30-2.5k; SON80P245X245X90-7N; Mouser Part Number 403-SGP30-2.5K
IC3: LM75BDP,118; SOP65P490X110-8N; Mouser Part Number 771-LM75BDP
IC4: OPT3001DNPR; SON65P200X200X65-7N-D; Mouser Part Number 595-OPT3001DNPR
IC5: TLV70018DDCR; SOT95P280X110-5N; Mouser Part Number 595-TLV70018DDCR
IC7: BSS138PS; SOT65P210X110-6N; Mouser Part Number N/A
J1, J2: Conn_02x08_Counter_Clockwise; PinSocket_2x08_P2.54mm_Vertical
JP1, JP3, JP4, JP6: SolderJumper_2_Open; R_0402_1005Metric; not fitted
JP2, JP5, JP7: SolderJumper_2_Open; R_0402_1005Metric
JP8: Jumper_2_Small_Open; SolderJumper-2_P1.3mm_Open_TrianglePad1.0x1.5mm
R1, R2, R3, R4, R7, R8: 10k; R_0402_1005Metric
R5, R6: 10k; R_0402_1005Metric; not fitted
TP2, TP3: TestPoint; TestPoint_Pad_D1.0mm

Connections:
3V3_GPIO: C1.1, C2.1, C5.1, C7.1, IC1.8 (VCC), IC3.7 (A0), IC3.8 (VCC), IC4.1 (VDD), IC4.2 (ADDR), IC5.1 (IN), IC5.3 (EN), J1.2, J1.16, J2.1, J2.15, JP1.2 (B), JP2.2 (B), JP4.2 (B), JP6.2 (B), R1.1, R2.1, R5.1, R6.1, R7.1, R8.1; also elsewhere on the board
+1V8: C3.1, C4.1, IC2.1 (VDD), IC2.5 (VDDH), IC5.5 (OUT), IC7.2 (G1), IC7.5 (G2), JP8.1 (A), R3.1, R4.1
GND: C1.2, C2.2, C3.2, C4.2, C5.2, C7.2, IC1.4 (VSS), IC1.9 (EP), IC2.2 (VSS), IC2.4 (R), IC2.7 (EP), IC3.4 (GND), IC3.5 (A2), IC3.6 (A1), IC4.3 (GND), IC4.7 (EP), IC5.2 (GND), J1.1, J1.15, J2.2, J2.16, JP3.1 (A), JP5.1 (A), JP7.1 (A); also elsewhere on the board
IO1: J1.3
IO2: J1.4
IO4_MOSI0: J1.5
IO5_MISO0: J1.6
IO6_SCLK0: J1.7
IO7_CS0: J1.8
IO8_SDA0: IC1.5 (SDA), J1.9
IO9_SCL0: IC1.6 (SCL), J1.10
IO10: J1.14
IO11: J1.13
IO34: J2.13; also elsewhere on the board
IO35_MISO1: J2.11
IO36_MOSI1: J2.12
IO37_CS1: J2.9
IO38_SCLK1: J2.10
IO39_SDA1: IC3.1 (SDA), IC4.6 (SDA), IC7.3 (D2), J2.8, R2.2, R5.2
IO40_SCL1: IC3.2 (SCL), IC4.4 (SCL), IC7.6 (D1), J2.7, R1.2, R6.2
IO41: IC3.3 (OS), J2.3, R8.2
IO42: IC4.5 (INT), J2.4, R7.2
IO48: J2.14; also elsewhere on the board
unnamed: IC1.1 (E0), JP2.1 (A), JP3.2 (B)
unnamed: IC1.2 (E1), JP4.1 (A), JP5.2 (B)
unnamed: IC1.3 (E2), JP6.1 (A), JP7.2 (B)
unnamed: IC1.7 (~WC), JP1.1 (A)
unnamed: J1.11, JP8.2 (B)
SCL1_1-8V: IC2.6 (SCL), IC7.1 (S1), R4.2, TP3.1
SDA1_1-8V: IC2.3 (SDA), IC7.4 (S2), R3.2, TP2.1

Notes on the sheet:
Addr: 1001001
Temp., Hum. Sensor
GPIO
Addr: 1000101
Bi-directional level shifter circuit
3V3 to 1V8 conversion
Gas sensor
Feature Board ID
https://www.lcsc.com/datasheet/lcsc_datasheet_2304140030_STMicroelectronics-M24C02-RMC6TG_C495258.pdf
Pullups
Addr: 1011000
https://electronics.stackexchange.com/questions/173297/how-does-a-bidirectional-level-shifter-work
Ambient Light Sensor

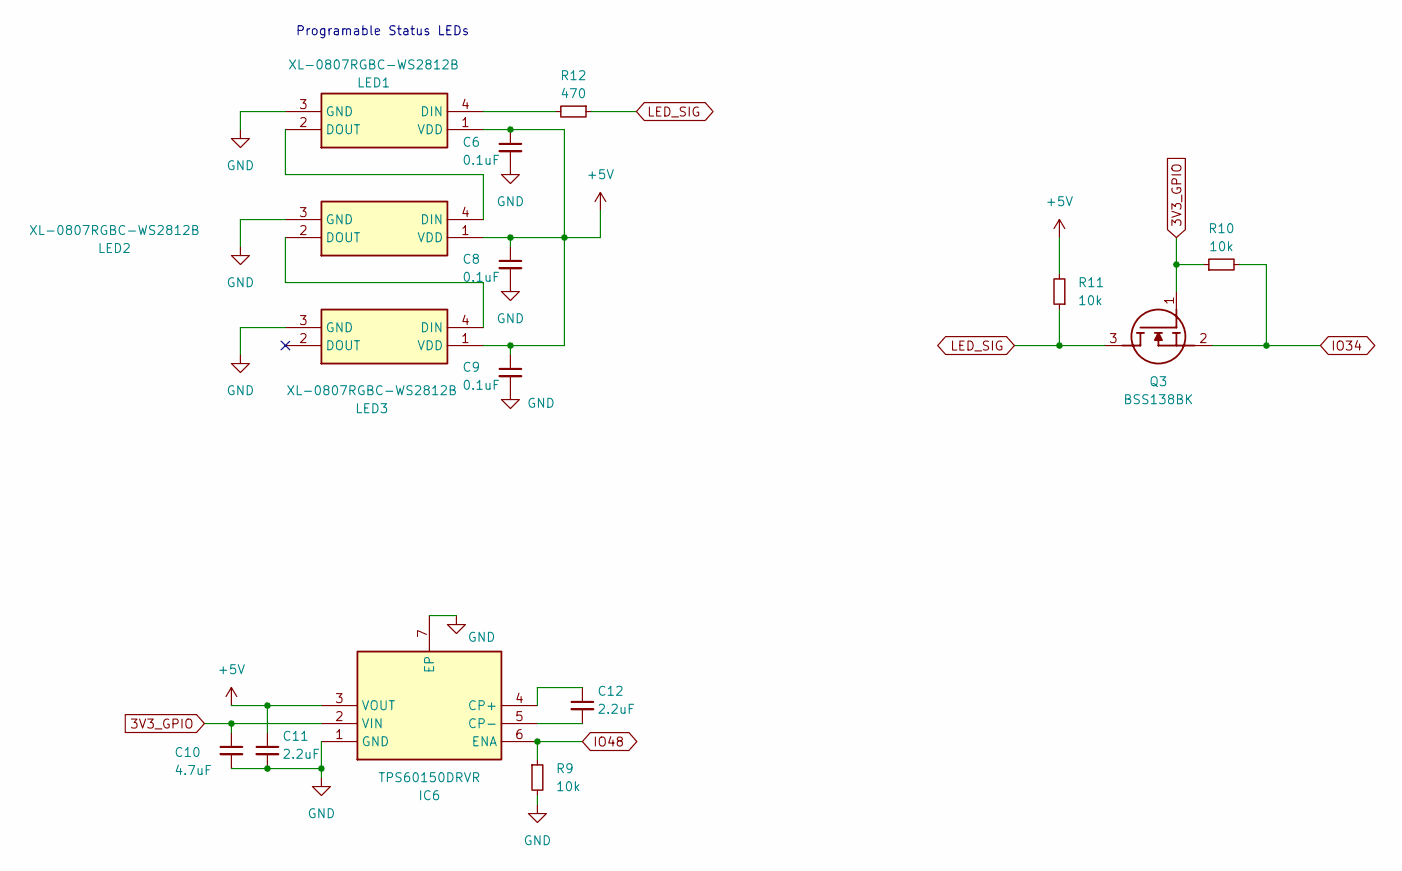
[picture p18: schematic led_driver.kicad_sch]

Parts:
C6, C8, C9: 0.1uF; C_0402_1005Metric
C10: 4.7uF; C_0402_1005Metric
C11, C12: 2.2uF; C_0402_1005Metric
IC6: TPS60150DRVR; SON65P200X200X80-7N; Mouser Part Number 595-TPS60150DRVR
LED1, LED2, LED3: XL-0807RGBC-WS2812B; XL0807RGBCWS2812B; Manufacturer_Part_Number XL-0807RGBC-WS2812B
Q3: BSS138BK; TL431CDBZR215; Mouser Part Number N/A
R9, R10, R11: 10k; R_0402_1005Metric
R12: 470; R_0402_1005Metric

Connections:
3V3_GPIO: C10.1, IC6.2 (VIN), Q3.1 (G), R10.1; also elsewhere on the board
+5V: C6.1, C8.1, C9.1, C11.1, IC6.3 (VOUT), LED1.1 (VDD), LED2.1 (VDD), LED3.1 (VDD), R11.2
GND: C6.2, C8.2, C9.2, C10.2, C11.2, IC6.1 (GND), IC6.7 (EP), LED1.3 (GND), LED2.3 (GND), LED3.3 (GND), R9.2; also elsewhere on the board
IO34: Q3.2 (S), R10.2; also elsewhere on the board
IO48: IC6.6 (ENA), R9.1; also elsewhere on the board
LED_SIG: Q3.3 (D), R11.1, R12.1
unnamed: C12.1, IC6.4 (CP+)
unnamed: C12.2, IC6.5 (CP-)
unnamed: LED1.4 (DIN), R12.2
unnamed: LED1.2 (DOUT), LED2.4 (DIN)
unnamed: LED2.2 (DOUT), LED3.4 (DIN)

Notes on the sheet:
Programable Status LEDs

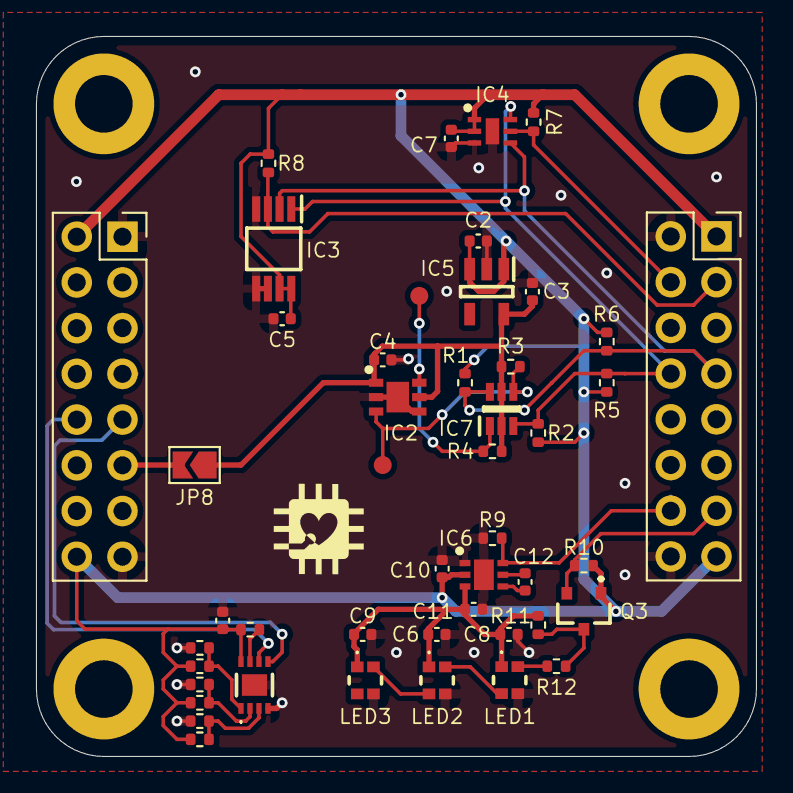
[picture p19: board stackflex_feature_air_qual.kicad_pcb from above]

Board: 2 copper layers, 40.0 x 40.0 mm, 51 parts (0 on the bottom side), 25 nets.

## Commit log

2024-12-29 core 2025.1.1 and air quality 2025.1.0
    [BOM-stackflex_core_2025-1-1.csv, BOM-stackflex_feature_air_qual_2025-1-0.csv, led_driver.kicad_sch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]
2025-01-11 add docu for v1.1
    [BOM-stackflex_core_2025-1-0.csv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]
